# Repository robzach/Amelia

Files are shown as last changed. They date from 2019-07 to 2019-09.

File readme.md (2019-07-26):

# 7/19/19: radio weirdness

Note: this is my first entry into this log but very much not the first work done on this project.

I kept running into a failure to transmit error while I was trying to run `ranger_transmitter` and `multi_receiver_print_serial`. I checked the wiring repeatedly and couldn't diagnose the problem. I disconnected the SDA and SCL lines running to the ranger, thinking perhaps they were interfering with the transmission, but that didn't help either. It was especially confusing since I'd been using only lightly modified code, with a nearly identical hardware setup, that worked very well on the Empathy Machine project only about a month ago. (That hardware has continued to work.)

The Empathy Machine code uses an acknowledge packet to return data to the requesting radio, which is a clever way of having one receiving radio that many transmitters send things to: the "receiver" actually sends out packets to one radio at a time, and the recipient of each packet responds only when called on. This prevents collisions and worked just fine the last time I tried it, as I've mentioned.

Shifting to a simpler model, I tried using the `simple_rx` and `simple_tx` sketches (found in the `examples and tests` folder) which mercifully finally worked…with a caveat. For some reason, about half of the packets seemed to be dropped. As in, the transmitter was sending one packet per second, and the receiver would only blink about half the time. Very confusing behavior, for two radios which are a foot apart from each other on a table. Perhaps this is an environment (a university campus) where there's enough 2.4GHz traffic to interfere with these attempts.

One note: I'm watching the little hardware TX lights to see when the transmitter is sending and when the receiver is receiving, and that makes it obvious when they're mismatched (because the transmitter is blinking like twice as much as the receiver). However! The blinking is perfectly in lockstep right until I open the serial connection on the computer attached to the receiver. Are `Serial.println()` executions the problem here? I don't think it's a timing issue, because even when I'm only transmitting one packet a second it's still dropping like half of them. Don't know.

## Next step: wired

I spent more time trying to get these wireless modules to work, and began investigating the strange data loss behavior, but it's a dark rabbit hole. Instead, I'm going to eschew the radio feature entirely—it was only implemented as a way of simplifying the prototyping I want to do. Instead, I'll rewrite the code so the one "receiver" and all the "transmitters" are simply wired together. I'll use software serial on all of them so that I can plug into their hardware UART via the serial monitor to update and debug as needed. And I'll just run a bunch of long wires to each module: two for power, and two for data. Hopefully the cable runs won't be so long that there's data quality problems…probably a 10 foot run won't be too much.

I could just move towards the likely final installation version of this, namely using RS485 modules since that's a safe/reasonable way to move signals over any sort of distance, with easy cabling, etc.

# 7/25/19 wires, but still not quite there

Lots of work was left out of this log, but now I've got all the devices with wired connections on the table. (I never figured out what was wrong with the radio connections.)

Currently all 5 sensors are sharing a UART bus with the data requesting unit, which is plugged into a computer. I have installed diodes on the TX lines of each sensor Arduino (facing *into* the Arduino, counterintuitively) so that the line has transmission integrity, but it's still not quite working right.

I'm only using the UART for one-directional communication. The requesting unit sends a brief pulse into a wire every 1 second, and each remote Arduino has an interrupt that's triggered by a falling voltage on pin `2`, where that's plugged in. Then each unit waits a certain amount of time before sending its data back to the requesting unit on the UART bus.

Important finding: if the remote (sensor) Arduinos aren't plugged into power, but are plugged into ground, then the voltage of the outgoing trigger signal drops unacceptably. Probably an unpowered Arduino doesn't have high impedance on a digital pin, and lets some leakage through to the ground that it *is* plugged into. In conclusion: don't simply unplug power on remote Arduinos for troubleshooting, as it will kill the trigger signal.

Transmission time for the message `#0:1234` at 9600 baud is observed as 9.36ms on the scope. That's good; it means that giving each transmission at 20ms intervals should be plenty of deadband in between.

**Found the problem!** There was a tiny, invisible electrical fault: one of the yellow wires in the UART bus appears to have been mashed into a ground pin, always holding the TX line low. I rearranged the wires and it's fixed. Now all five devices are sending their own data to the requester, reliably.

Next up: try a higher data speed, hopefully while maintaining data integrity. Have been using 9600 baud, and I'll just leap up to 115200 to see what happens. If it's transmitting good data, then the messages can be crammed into a much narrower frame, and more messages can be sent per second overall.

Results: 19200 baud is the fastest baud rate that successfully transmits data across the ~6' twisted wires; above that the inductance and/or capacitance of the wire isn't getting good data to the far end. Of course, using RS485 transmitters would solve this problem entirely and permit for much higher data transmission rates. Requests for new data should be sent no more often than every 200ms, or data from the prior request will overlap and cause errors.

**Adding a Processing sketch** to graph the data, which is doing something, but not drawing good graphs yet.

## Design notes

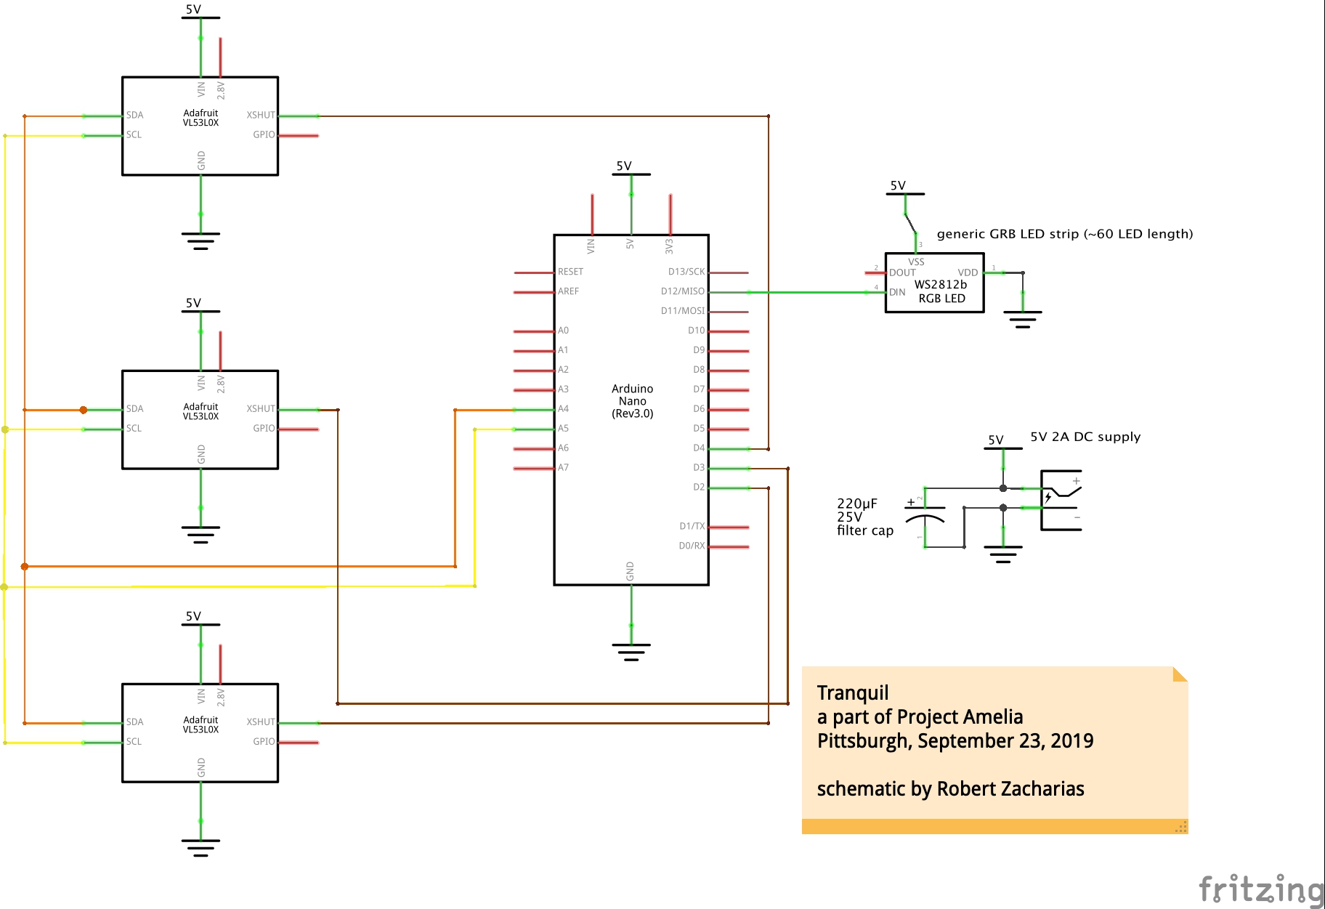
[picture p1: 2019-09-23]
production/electronics/Tranquil_schematic.jpg

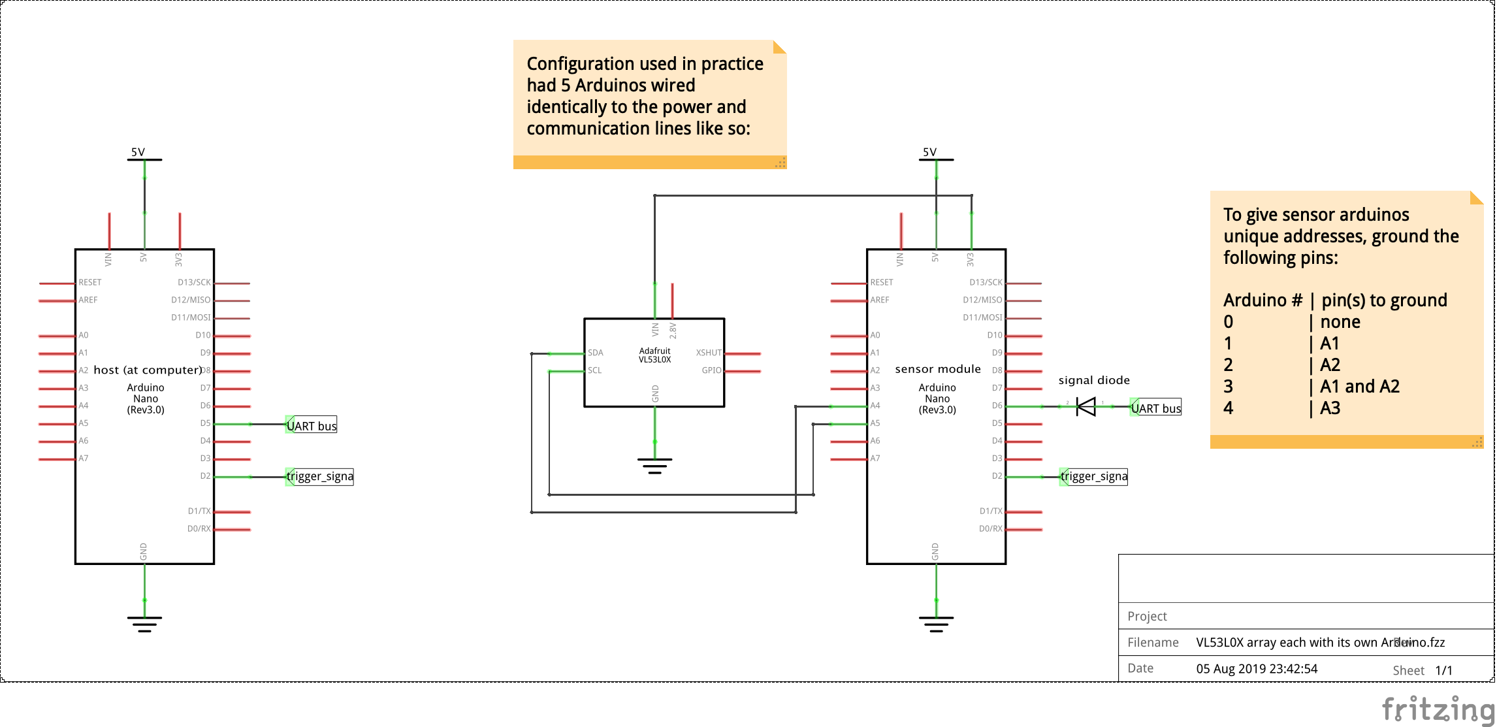
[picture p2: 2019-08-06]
earlier_development/schematics/VL53L0X array each with its own Arduino_schem.png

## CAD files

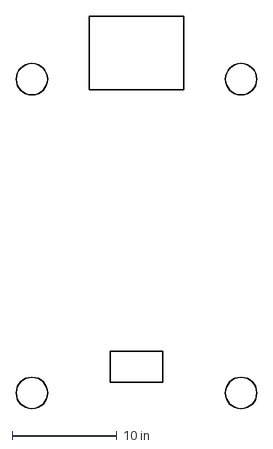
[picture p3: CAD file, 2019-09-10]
earlier_development/fabrication_drawings/test_sensor_cutout.dxf
23.0 x 37.5 in

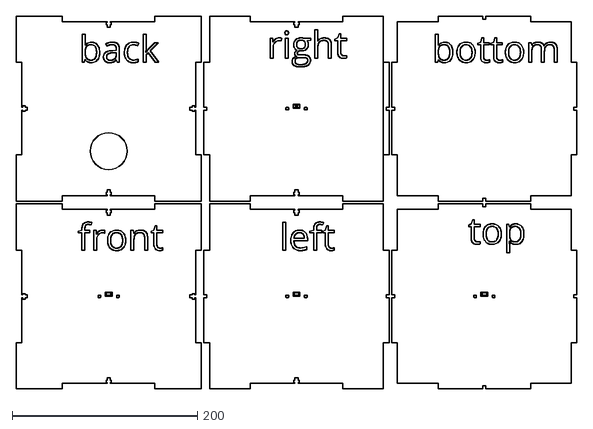
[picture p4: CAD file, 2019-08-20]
earlier_development/fabrication_drawings/#box_with_sensor_cutouts.dxf
606.0 x 403.0

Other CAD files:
earlier_development/fabrication_drawings/box_with_sensor_cutouts.dxf

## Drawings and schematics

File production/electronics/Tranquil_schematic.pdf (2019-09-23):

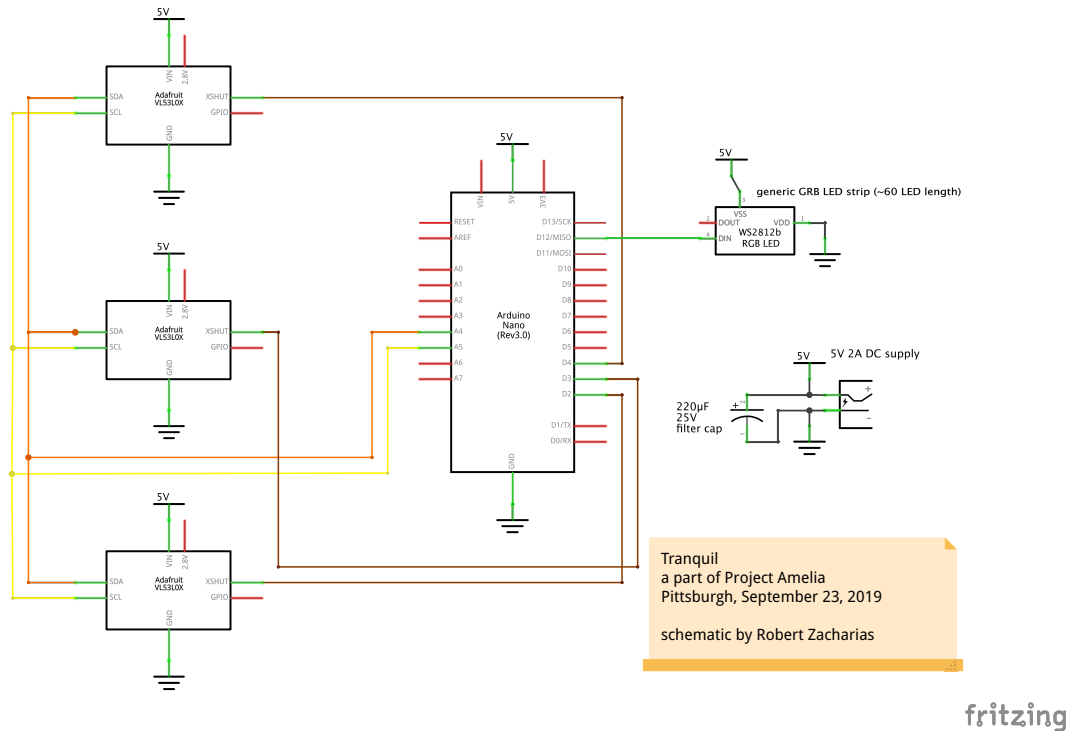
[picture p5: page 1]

Tranquil
a part of Project Amelia
Pittsburgh, September 23, 2019

schematic by Robert Zacharias

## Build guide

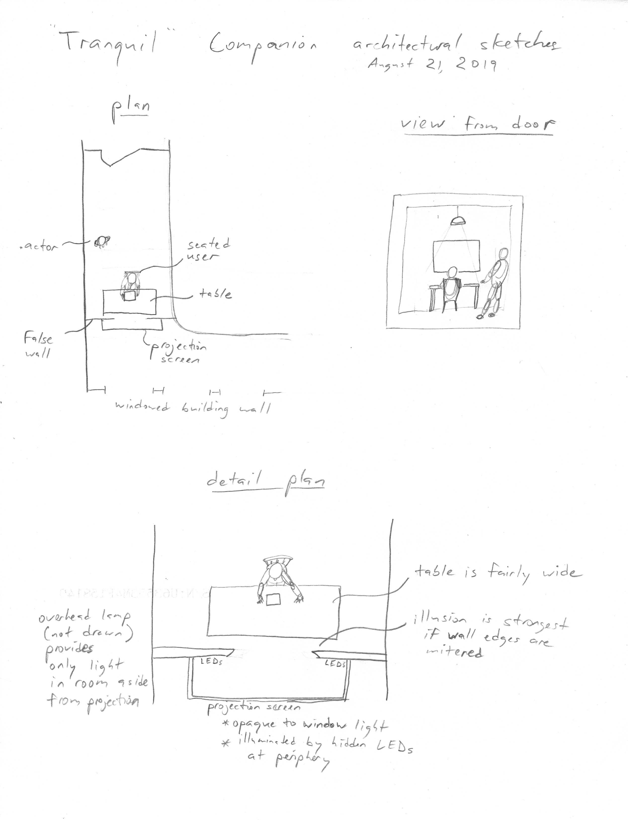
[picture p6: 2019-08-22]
earlier_development/fabrication_drawings/Tranquil Companion architectural sketch.jpeg

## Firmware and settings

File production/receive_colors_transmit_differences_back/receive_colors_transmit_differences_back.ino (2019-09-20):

// updating 9-8-19 with byte-based serial communication


#include <PololuLedStrip.h>
#include <Wire.h>
#include <VL53L0X.h>

//#define HIGH_SPEED

const int LED_STRIP_PIN = 12; // WS2801 LED strip data line is plugged into this pin

PololuLedStrip<LED_STRIP_PIN> ledStrip;
const int LED_COUNT = 60;
rgb_color colors[LED_COUNT]; // Create a buffer for holding the colors (3 bytes per color).

const int NUM_SENSORS = 3;
const byte START_ADDRESS = 29; // first I2C address to provision (the rest will increment)
const long SERIAL_SPEED = 57600; // serial communication baud rate

const int DEBUGPIN1 = 10; // used for oscope monitoring of various events

const bool DEBUG = false;

bool newDataRecd = false;
int counter = 0;

// incoming color data from Processing:
// a sensor instruction byte, three color bytes 0–254 each, a checksum, and a 255 terminator
byte readIn[6];

// data to return to Processing:
// three sensor positions, a checksum, and a 255 terminator
byte sendData[5];



VL53L0X sensor[NUM_SENSORS];
int sensorValues[NUM_SENSORS] = {}; // values to transmit


void setup() {
  Serial.begin(SERIAL_SPEED);
  Wire.begin();

  pinMode(DEBUGPIN1, OUTPUT);
  digitalWrite(DEBUGPIN1, LOW);

  // set up Arduino output pins to connect with each sensor's XSHUT (shutdown) input
  for (int i = 0; i < NUM_SENSORS; i++) {
    pinMode(i + 2, OUTPUT); // start at digital pin 2 and increment from there
    digitalWrite(i + 2, LOW); // shut down all the sensors to start with
  }

  // initialize each sensor individually
  for (int i = 0; i < NUM_SENSORS; i++) {

    digitalWrite(i + 2, HIGH); // turn them on one at a time
    delay(100); // wait a bit to ensure that sensor is ready to receive an instruction

    // assign a new address to that sensor
    sensor[i].init();
    sensor[i].setTimeout(500);
    sensor[i].setAddress(i + START_ADDRESS);
    if (DEBUG) Serial.println((String)"sensor: " + i + ", address: " + (i + START_ADDRESS));

#if defined HIGH_SPEED
    // reduce timing budget to 20 ms (default is about 33 ms)
    sensor[i].setMeasurementTimingBudget(20000);
#elif defined HIGH_ACCURACY
    // increase timing budget to 200 ms
    sensor[i].setMeasurementTimingBudget(200000);
#endif
  }
}

void loop() {
  // the serial event catches incoming color data and flips newDataRecd true
  if (newDataRecd) {
    writeColorsToLEDs();
    scanSensorsTransmitResponse();
    newDataRecd = false;
  }
}

void serialEvent() {
  while (Serial.available()) {
    readIn[counter] = Serial.read();
  }
  if (readIn[counter] == 255) { // terminator received
    if (checksumValid(readIn)) newDataRecd = true;
    counter = 0; // and reset counter

    // reply with checksum result followed by terminator
    //    Serial.write(checksumValid(readIn)); Serial.write(255);
    //    Serial.write(readIn, counter); // write values prior to terminator
    //    Serial.write(255); // and write a terminator at the end
  }
  else counter++; // otherwise, proceed through loop
}

void writeColorsToLEDs() {
  rgb_color color;
  color.green = readIn[1];
  color.red = readIn[2];
  color.blue = readIn[3];

  for (uint16_t i = 0; i < LED_COUNT; i++) colors[i] = color;

  // Write to the LED strip.
  // time to execute this write (with 60 LEDs) measured at ~4ms
  ledStrip.write(colors, LED_COUNT);
}

void scanSensorsTransmitResponse() {
  // scan only the sensors indicated by the zeroth byte received from Processing
  bool readSensor0 = readIn[0] & 0b1; // ones bit
  bool readSensor1 = (readIn[0] >> 1) & 0b1; // twos bit
  bool readSensor2 = (readIn[0] >> 2) & 0b1; // fours bit

//  readSensor0 = readSensor1 = readSensor2 = true;

  // array to hold values prior to reducing them to bytes
  int distVals[3];
  if (readSensor0) distVals[0] = sensor[0].readRangeSingleMillimeters();
  if (readSensor1) distVals[1] = sensor[1].readRangeSingleMillimeters();
  if (readSensor2) distVals[2] = sensor[2].readRangeSingleMillimeters();

//  for (int i = 0; i < 3; i++){
//    Serial.print(distVals[i]);
//    Serial.print(" "); 
//  } Serial.println();

  // slice millimeter values into 255 bins
  // assumes max meaningful distance is 500mm = 50cm
  for (int i = 0; i < 3; i++) {
    distVals[i] = map(constrain(distVals[i], 0, 500), 0, 500, 0, 254);
  }

  // buffer to hold values to write out, plus a checksum and a terminator at the end
  byte writeBuf[3 + 2] = {}; // need this to zero all values instead of holding over!!

  // load sliced values into byte array
  for (int i = 0; i < 3; i++) {
    writeBuf[i] = distVals[i];
  }

  // add checksum to penultimate position in writeBuf array
  for (int i = 0; i < 3; i++) {
    writeBuf[3] += (writeBuf[i] * (i + 1));
  } // checksum is computed: (0th data point + (1st data point * 2) + (2nd data point * 3) + ...)

  // finally, write value 255 to final position of array to serve as terminator
  writeBuf[3 + 1] = 255;

  Serial.write(writeBuf, 5);

  //
  //  for (int i = 0; i<5; i++){
  //    sendData[i] = writeBuf[i];
  //  }
  //
//    sendData[5] = 255; // last bit is terminator
}

// checksum should be at penultimate array position, and 255 (terminator) at the end
boolean checksumValid (byte * arrayIn) {
  // you can't run sizeof(array) because you just get the size of the pointer to that array
  // instead find the passed in array's length by finding the position of the 255 terminator
  int length = 0;
  while (arrayIn[length] < 255) length++;
  length++; // after above while() exits, length contains the index of the 255 value; increment to calculate length of array

  byte localChecksum = 0;
  // add zeroth through second-to-last element in incoming data
  for (int i = 0; i < length - 2; i++) {
    localChecksum += (arrayIn[i] * (i + 1));
  }

  // special case: change 255 checksum to 254
  if (localChecksum == 255) localChecksum = 254;

  //  localChecksum = arrayIn[0] + (arrayIn[1] * 2) + (arrayIn[2] * 3);

  // penultimate element of array is checksum, so compare to penultimate value read in for result
  return (localChecksum == arrayIn[length - 2]);
}

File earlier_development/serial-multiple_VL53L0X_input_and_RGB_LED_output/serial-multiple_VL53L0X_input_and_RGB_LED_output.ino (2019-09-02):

/*
    Multiple VL53L0X sensors are read via shared I2C bus; this is a data input to the device.
    It also has a short length of addressable RGB LED strip on it, which is a data output.

    Distance input information:

        Distance values are reported, space-delimited, via serial port. Sample data looks like:

        263 307 144 8190

        Note that the value 8190 is what the sensor typically reports when the target surface
        is out of range.

        Each VL53L0X sensor's wiring:

          VCC to Arduino 5V (red wire)
          GND to Arduino ground (black wire)
          SCL to Arduino A5 (yellow wire)
          SDA to Arduino A4 (white wire)
          XSHUT incrementally starting at Arduino digital pin 2 (brown wire)
          (first sensor wires XSHUT to Arduino pin 2, second sensor wires XSHUT to Arduino pin 3, etc.)

        Based on Pololu's VL53L0X example code; their original text below:

        "This example shows how to get single-shot range
        measurements from the VL53L0X. The sensor can optionally be
        configured with different ranging profiles, as described in
        the VL53L0X API user manual, to get better performance for
        a certain application. This code is based on the four
        "SingleRanging" examples in the VL53L0X API.
        The range readings are in units of mm."

    LED output information:

        The LED strip is wired VCC to the Arduino's 5V; ground to the Arduino's ground; and
        the signal pin goes to Arduino pin 12.

        Incoming data comes in the form "R,G,B" and must be delimited (though it need not be
        comma delimited necessarily). The serial to int process relies on parseInt, which can be blocking,
        so I might need to work on it.

        The logic is drawn straight from Pololu's example sketch, "LedStripColorTester."

  Robert Zacharias, 8-12-19

*/

#include <Wire.h>
#include <VL53L0X.h>
#include <PololuLedStrip.h>

const int NUM_SENSORS = 4;
const byte START_ADDRESS = 29; // first I2C address to provision (the rest will increment)
const long SERIAL_SPEED = 9600; // serial communication baud rate
const int LED_STRIP_PIN = 12; // WS2801 LED strip data line is plugged into this pin

// Set this bool to true for some serial debugging messages
// (Note: these messages will clutter the serial feedback, probably making it unreadable
// to software that's parsing out the returned distance values.)
const bool DEBUG = false;

// flag to send data only after spoken to: go true when data received, then transmit
// data back, then go false
bool transmitNow = false;

PololuLedStrip<LED_STRIP_PIN> ledStrip;
const int LED_COUNT = 60;
rgb_color colors[LED_COUNT]; // Create a buffer for holding the colors (3 bytes per color).

VL53L0X sensor[NUM_SENSORS];


// Uncomment the below #define to use long range mode. This
// increases the sensitivity of the sensor and extends its
// potential range, but increases the likelihood of getting
// an inaccurate reading because of reflections from objects
// other than the intended target. It works best in dark
// conditions.

//#define LONG_RANGE


// Uncomment ONE of these two #defines to get
// - higher speed at the cost of lower accuracy OR
// - higher accuracy at the cost of lower speed

//#define HIGH_SPEED
//#define HIGH_ACCURACY


void setup()
{
  Serial.begin(SERIAL_SPEED);
  Serial.setTimeout(100); // only wait 100 milliseconds to parse malformed input
  Wire.begin();

  // set up Arduino output pins to connect with each sensor's XSHUT (shutdown) input
  for (int i = 0; i < NUM_SENSORS; i++) {
    pinMode(i + 2, OUTPUT); // start at digital pin 2 and increment from there
    digitalWrite(i + 2, LOW); // shut down all the sensors to start with
  }

  // initialize each sensor individually
  for (int i = 0; i < NUM_SENSORS; i++) {

    digitalWrite(i + 2, HIGH); // turn them on one at a time
    delay(100); // wait a bit to ensure that sensor is ready to receive an instruction

    // assign a new address to that sensor
    sensor[i].init();
    sensor[i].setTimeout(500);
    sensor[i].setAddress(i + START_ADDRESS);
    if (DEBUG) Serial.println((String)"sensor: " + i + ", address: " + (i + START_ADDRESS));

#if defined LONG_RANGE
    // lower the return signal rate limit (default is 0.25 MCPS)
    sensor[i].setSignalRateLimit(0.1);
    // increase laser pulse periods (defaults are 14 and 10 PCLKs)
    sensor[i].setVcselPulsePeriod(VL53L0X::VcselPeriodPreRange, 18);
    sensor[i].setVcselPulsePeriod(VL53L0X::VcselPeriodFinalRange, 14);
#endif

#if defined HIGH_SPEED
    // reduce timing budget to 20 ms (default is about 33 ms)
    sensor[i].setMeasurementTimingBudget(20000);
#elif defined HIGH_ACCURACY
    // increase timing budget to 200 ms
    sensor[i].setMeasurementTimingBudget(200000);
#endif
  }
}

void loop()
{
  if (transmitNow) writeSensorValuesOut();
  readLEDColorIn();
}

void writeSensorValuesOut() {
  for (int i = 0; i < NUM_SENSORS; i++) {
    Serial.print(sensor[i].readRangeSingleMillimeters());
    if (sensor[i].timeoutOccurred() && DEBUG) {
      Serial.print(" TIMEOUT");
    }
    if (i != NUM_SENSORS - 1) Serial.print(' '); // space delimit between values
  }
  Serial.println();
  transmitNow = false; // switch flag to not send data
}

void readLEDColorIn() {
  if (Serial.available())
  {
    char c = Serial.peek();
    if (!(c >= '0' && c <= '9'))
    {
      Serial.read(); // Discard non-digit character
    }
    else
    {
      // Read the color from the computer.
      rgb_color color;
      color.red = Serial.parseInt();
      color.green = Serial.parseInt();
      color.blue = Serial.parseInt();

      // Update the colors buffer.
      for (uint16_t i = 0; i < LED_COUNT; i++)
      {
        colors[i] = color;
      }

      // Write to the LED strip.
      ledStrip.write(colors, LED_COUNT);

      transmitNow = true; // switch flag to send data

      if (DEBUG) {
        Serial.print("Showing color: ");
        Serial.print(color.red);
        Serial.print(",");
        Serial.print(color.green);
        Serial.print(",");
        Serial.println(color.blue);
      }
    }
  }
}

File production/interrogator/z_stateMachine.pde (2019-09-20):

void stateMachine() {
  // only print console feedback "entering mode: MODE" if changed from prior mode (for debugging)
  boolean change = (prevMode != mode) ? true : false;

  switch (mode) {
  case ORIENTATION:
    if (change) {
      println("entering mode: " + mode);
      prevMode = mode;
      // when just entering mode, set counter to 0
      stageCounter = 0; // used to step through stages in orientation
    }
    orientation(); 

    // if start signal received while in Orientation, move to idle
    if (braceletTap) {
      braceletTap = false; // flip it back after acknowledge
      mode = Mode.IDLE;
    }
    break;
  case INTERROGATION:
    if (change) {
      println("entering mode: " + mode);
      prevMode = mode;
      stageCounter = 0; // reset stage counter for new mode
    }
    interrogation();

    // if start signal received while in interrogation, move to idle
    if (braceletTap) {
      braceletTap = false; // flip it back after acknowledge
      mode = Mode.IDLE;
    }
    break;
  case TERMINATION: 
    if (change) {
      println("entering mode: " + mode);
      prevMode = mode;
    }
    termination(); 
    break;
  case IDLE:
  default:
    if (change) {
      println("entering mode: " + mode);
      prevMode = mode;

      // triggers once upon entering IDLE mode
      // slow fading in and out of white
      breaths[0] = new Breathe(true, 0, 15000);  // red
      breaths[1] = new Breathe(true, 1, 15000); // green
      breaths[2] = new Breathe(true, 2, 15000); // blue
    }

    idle();

    // if start signal received, move to orientation mode
    if (braceletTap) {
      braceletTap = false; // flip it back after acknowledge
      mode = Mode.ORIENTATION;
    }

    break;
  }
}

long startTime = 0;

void idle() {
  if (millis() - startTime > 1000) {
    startTime = millis();
  }

  // updates all breathing functions, only for those objects currently wanting to be run
  for (Breathe breath : breaths) {
    if (breath.getActive()) {
      breath.pollBreathe();
    }
  }
}

void orientation() {
  // start timer to begin
  if (stageCounter == 0) {
    startTime = millis(); 
    stageCounter = 1;
    for (int i = 0; i < 3; i++) colors[i] = 0; // zero out colors
    transmitBytes();
  }

  // start with left-side-of-box sensor training for 10 seconds
  if (stageCounter == 1) {
    if (millis() - startTime < 10000) redScale();
    else {
      stageCounter = 2;
      startTime = millis();
      for (int i = 0; i < 3; i++) colors[i] = 0; // zero out colors
    }
  }


  // right-side-of-box sensor training for 10 seconds
  if (stageCounter == 2) {
    if (millis() - startTime < 10000) blueScale();
    else {
      stageCounter = 3;
      startTime = millis();
      for (int i = 0; i < 3; i++) colors[i] = 0; // zero out colors
    }
  }

  // top-side-of-box sensor training for 10 seconds
  if (stageCounter == 3) {
    if (millis() - startTime < 10000) greenScale();
    else {
      stageCounter = 4;
      startTime = millis();
      for (int i = 0; i < 3; i++) colors[i] = 0; // zero out colors
    }
  }

  //once complete, revert to IDLE mode
  if (stageCounter == 4) mode = Mode.INTERROGATION;
}


void interrogation() {
  // pulse different lights up and down through a sequence of brightnesses
  // these are described by the switch(case) statements below (as is the 

  if (millis() > nextSingleTime) {
    int stepTime = 0;
    switch(counter) {
    case 0:
      breaths[0] = new Breathe(true, 0, 2000);  // red breathing sequence
      stepTime = 10000;
      break;
    case 1:
      breaths[0].setActive(false);
      breaths[1] = new Breathe(true, 1, 1000); // green breathing sequence
      stepTime = 10000;
      break;
    case 2:
      breaths[1].setActive(false);
      breaths[2] = new Breathe(true, 2, 750); // blue breathing sequence
      stepTime = 10000;
      break;
    case 3:
      breaths[2].setActive(false);
      breaths[1] = new Breathe(true, 0, 1000); // red breathing sequence
      stepTime = 10000;
      break;
    case 4:
      breaths[1].setActive(false);
      breaths[0] = new Breathe(true, 0, 1000); // red breathing sequence
      stepTime = 500;
      break;
    case 5:
      // note that breaths[2] is still running from the previous case
      breaths[2] = new Breathe(true, 2, 1000); // blue sequence to run concurrently with red
      stepTime = 9500;
      break;
    case 6:
      breaths[0].setActive(false); // turn everything off
      breaths[2].setActive(false); // turn everything off
      break;
    case 7:
      counter = 0; // counter reset added by Mike to fix bug
      mode = Mode.TERMINATION;
      break;
    default:  // if it breaks, go to IDLE mode
      mode = Mode.IDLE;
      break;
    }
    counter++; // increment for next case to get called next time
    for (int i = 0; i < 3; i++) colors[i] = 0; // zero out colors in between steps
    nextSingleTime = millis() + stepTime; // set up next time this if goes true
  }

  // updates all breathing functions, only for those objects currently wanting to be run
  for (Breathe breath : breaths) {
    if (breath.getActive()) {
      breath.pollBreathe();
    }
  }
}

void termination() {

  // flashes red and blue a bunch of times quickly
  // (blocking code! Probably doesn't matter at this point, though)
  for (int i = 0; i < 20; i++) {
    colors[0] = 254; // red
    colors[2] = 0; // no blue
    transmitBytes();
    delay(100);
    colors[0] = 0; // no red
    colors[2] = 255; // blue
    transmitBytes();
    delay(100);
  }
  mode = Mode.IDLE;
}


/*
old version using individually called pollBreathe() functions
 void interrogation() {
 // pulse different lights up and down through a sequence of brighnesses
 
 if (stageCounter == 0) {
 startTime = millis(); 
 for (int i = 0; i < 3; i++) colors[i] = 0; // zero out colors
 transmitBytes();
 stageCounter = 1;
 }
 
 if (stageCounter == 1) {
 breaths[0] = new Breathe(true, 0, 2000);  // begin red breathing sequence
 startTime = millis();
 stageCounter = 2;
 }
 
 if (stageCounter == 2) {
 if (millis() - startTime < 10000) { // if it's been less than 10 seconds
 breaths[0].pollBreathe(); // update that one breath command
 println(breaths[0].testBreathe());
 } else { // it's been more than 10 seconds
 breaths[1] = new Breathe(2, 1500); // begin blue breathing sequence
 for (int i = 0; i < 3; i++) colors[i] = 0; // zero out colors
 startTime = millis();
 stageCounter = 3;
 }
 }
 
 if (stageCounter == 3) {
 if (millis() - startTime < 10000) { 
 breaths[1].pollBreathe(); // run breaths[1]
 } else {
 breaths[2] = new Breathe(1, 1000);
 for (int i = 0; i < 3; i++) colors[i] = 0; // zero out colors
 startTime = millis();
 stageCounter = 4;
 }
 }
 
 if (stageCounter == 4) {
 if (millis() - startTime < 10000) { 
 breaths[2].pollBreathe(); // run breaths[2]
 } else {
 stageCounter = 5;
 }
 }
 
 if (stageCounter == 5) mode = Mode.IDLE;
 }
 */

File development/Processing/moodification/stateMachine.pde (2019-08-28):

void stateMachine() { //<>//
  // only print console feedback "entering MODE mode" if changed from prior mode (for debugging)
  boolean change = (prevMode != mode) ? true : false;

  switch (mode) {
  case INTRO:
    if (change) {
      println("entering " + mode + " mode");
      prevMode = mode;
    }
    rangerTrainingSequence();
    break;
  case CALMING:
    if (change) {
      println("entering " + mode + " mode");
      prevMode = mode;
    }
    calming(); 
    break;
  case DISORIENTATION:
    if (change) {
      println("entering " + mode + " mode");
      prevMode = mode;
    }
    disorientation(); 
    break;
  case INTERROGATION:
    if (change) {
      println("entering " + mode + " mode");
      prevMode = mode;
    }
    interrogation(); 
    break;
  case TERMINATION: 
    if (change) {
      println("entering " + mode + " mode");
      prevMode = mode;
    }
    termination(); 
    break;
  case IDLE: 
  default:
    if (change) {
      println("entering " + mode + " mode");
      prevMode = mode;
    }
    waitForStartSignal(); 
    break;
  }
}

long startTime = 0; 

void rangerTrainingSequence() {

  // start timer to begin
  if (stageCounter == 0) {
    startTime = millis();
    stageCounter = 1;
  }

  // run redAdjuster for 10 seconds
  if (stageCounter == 1) {
    if (millis() - startTime < 10000) redAdjuster();
    else {
      stageCounter = 2;
      startTime = millis();
    }
  }

  // run blueAdjuster for 10 seconds
  if (stageCounter == 2) {
    if (millis() - startTime < 10000) blueAdjuster();
    else {
      stageCounter = 3;
      startTime = millis();
    }
  }

  // run greenAdjuster for 10 seconds
  if (stageCounter == 3) {
    if (millis() - startTime < 10000) greenAdjuster();
    else {
      startTime = millis(); // reset timer
      mode = Mode.DISORIENTATION; // jump to next mode
    }
  }
}

void disorientation() {
  //greenBreathe(0);
  //redBreathe();
  //blueBreathe(0);

  if (millis() - startTime < 10000) redBounce(300); // run redBounce for 10 seconds
  else  mode = Mode.TERMINATION; // jump to next mode
}

void interrogation() {
}

void termination() {
  // fade all up to white and then back down to black
  for (int i = 0; i < 256; i++) {
    writeOut(i + "," + i + "," + i + "\n");
    delay(10);
  }
  for (int i = 255; i > 0; i--) {
    writeOut(i + "," + i + "," + i + "\n");
    delay(10);
  }
  mode = Mode.IDLE;
}

void waitForStartSignal() {
}

float redBreathe() {
  // establishes a breathing goal (driven via sine) for hand movement by left hand

  // used for running average computation; closer to 0 is longer memory and closer to 1 is faster updating
  float decayRate = 0.03; 

  float sinArgument = map(millis() % breathingTempo, 0, breathingTempo, 0, TWO_PI); // feed sine [0,2*PI] based on millis()
  float goal = map (sin(sinArgument), -1, 1, 0, 500) ; // turn sine's output to 0 to 500 (millimeters)
  float breatheDelta = goal - left;
  runningAverageDelta = (breatheDelta * decayRate) + (runningAverageDelta * (1-decayRate));
  //println("breathe goal = " + goal + ", current position = " + left + ", delta = " + breatheDelta + ", runningAverageDelta = " + runningAverageDelta);

  //demonstrate the breathing goal with the red LED output
  int redVal = int(map(goal, 0, 500, 0, 255));
  //writeOut(redVal + ",0,0\n");

  pushMatrix();
  translate(TASKAREALEFTEDGE, 300);
  fill(255);
  text("red is goal, yellow is current position\nwhite line is delta\nrunningAverageDelta = " + runningAverageDelta +
    "\nbreatheDelta = " + breatheDelta, 0, 20);
  noStroke();
  fill(255, 0, 0);
  ellipse( map(goal, 0, 500, 200, 0), 0, 20, 20); // goal dot (note flipped axis)
  fill(255, 255, 0);
  ellipse( map(left, 0, 500, 200, 0), 0, 10, 10); // current position dot (note flipped axis)
  stroke(255);

  float graphRunningAverageDelta = map(runningAverageDelta, 0, 500, 0, 200);
  line(map(left, 0, 500, 200, 0), 0, map(left, 0, 500, 200, 0) - graphRunningAverageDelta, 0); 

  popMatrix();

  return runningAverageDelta;
}


float blueBreathe(int sync) {
  // establishes a breathing goal (driven via sine) for hand movement by right hand

  // used for running average computation; closer to 0 is longer memory and closer to 1 is faster updating
  float decayRate = 0.03; 

  // if argument "sync" is 0, run in parallel to redBreathe, otherwise run them 180º separately
  float sinArgument;
  if (sync == 0) sinArgument = map(millis() % breathingTempo, 0, breathingTempo, 0, TWO_PI); // feed sine [0,2*PI] based on millis()
  else sinArgument = map(millis() % breathingTempo, 0, breathingTempo, TWO_PI, 0); // or to put it 180º out of phase, feed it[2*PI,0]
  float goal = map (sin(sinArgument), -1, 1, 0, 500) ; // turn sine's output to 0 to 500 (millimeters)
  float breatheDelta = goal - right;
  runningAverageDelta = (breatheDelta * decayRate) + (runningAverageDelta * (1-decayRate));
  //println("breathe goal = " + goal + ", current position = " + left + ", delta = " + breatheDelta + ", runningAverageDelta = " + runningAverageDelta);

  //demonstrate the breathing goal with the blue LED output
  int blueVal = int(map(goal, 0, 500, 0, 255));
  //writeOut(redVal + ",0,0\n");

  pushMatrix();
  translate(TASKAREALEFTEDGE+250, 300);
  fill(255);
  text("blue is goal, yellow is current position\nwhite line is delta\nrunningAverageDelta = " + runningAverageDelta +
    "\nbreatheDelta = " + breatheDelta, 0, 20);
  noStroke();
  fill(0, 0, 255);
  ellipse( map(goal, 0, 500, 0, 200), 0, 20, 20); // goal dot (not flipped: moving to right)
  fill(255, 255, 0);
  ellipse( map(right, 0, 500, 0, 200), 0, 10, 10); // current position dot (not flipped: moving to right)
  stroke(255);

  float graphRunningAverageDelta = map(runningAverageDelta, 0, 500, 0, 200);
  line(map(right, 0, 500, 0, 200), 0, map(right, 0, 500, 0, 200) + graphRunningAverageDelta, 0); 

  popMatrix();

  return runningAverageDelta;
}
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

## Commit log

2019-07-19 many updates, though still getting a transmit error which prevents any radio stuff from working
    [multi_receiver_print_serial.ino, ranger_transmitter.ino]
2019-07-19 added test code for wireless communication, later abandoned as too buggy for unkonwn reason
    [simple_rx.ino, simple_rx_with_ranger_data.ino, simple_tx.ino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]
2019-07-25 call_listen and listen_respond are working as currently configured.
2019-07-26 first pass at a Processing sketch to read and graph the data (not working yet)
    [graph.pde]
2019-07-26 these are the actual working files for wired communication; those in <a44183> were *not* the correct, working ones
    [call_listen.ino, listen_respond.ino]
2019-08-05 starting schematic of multi-Arduino VL53L0X array
    [VL53L0X array each with its own Arduino.fzz]
2019-08-06 completed schematic of V53L0X-and-Arduino array
    [VL53L0X array each with its own Arduino.fzz]
2019-08-08 initial upload; sketch is working reading multiple sensors
2019-08-09 drawing for simple box fabrication
    [box_with_sensor_cutouts.dxf]
2019-08-09 test expansion of cutout for VL53L0X
    [test_sensor_cutout.dxf]
2019-08-09 updated with bigger sensor holes and using R14 DXF format in a bid to make the units work automatically
    [box_with_sensor_cutouts.dxf]
2019-08-13 initial commit; currently does a serial read but not repeatedly writing
2019-08-13 added simple sample of how to send color data (not yet reliable)
2019-08-15 reordered code for legibility; changed to space-delimited data; fixed bug where final data point was being missed
    [graph.pde]
2019-08-20 organized many files/folders
    [VL53L0X array each with its own Arduino.fzz, box_with_sensor_cutouts.dxf, test_sensor_cutout.dxf]
2019-08-20 added fabrication drawings and moved files to earlier_development
    [#box_with_sensor_cutouts.dxf]
2019-08-21 further work on state machine, including eliminating blocking code as much as possible (no more loops). Top sensor data added as well. Intro sequence more fully fleshed out.
2019-09-01 adding SPI communication folder
2019-09-02 adding Processing SPI file
2019-09-02 tried different serial ports, nothing seemed to be working to communicate with the Arduino
2019-09-02 added flag to only send serial data when it's received, this may have broken communication but it's not clear
    [serial-multiple_VL53L0X_input_and_RGB_LED_output.ino]
2019-09-06 closer to communication purely by byte arrays (faster, less error prone?)
    [writing_bytes_for_color.pde]
2019-09-08 successfull sending bytes from Processing to Arduino, parsing, adding 1 to each value, sending back. *NOT* successfully parsing reply on Processing side.
2019-09-08 this file actually successfully sends values 0–254, Arduino reads and responds, and it turns returned values into ints correctly
    [simpler_byte_array_writing_reading.pde]
2019-09-08 successfully sending byte data from Processing to Arduino, checksumming, and replying to Processing
2019-09-09 cranked serial speed up to 57600 without apparent data integrity loss. Saves a couple milliseconds.
2019-09-10 moved all stale development work into earlier_development
    [#box_with_sensor_cutouts.dxf, box_with_sensor_cutouts.dxf, test_sensor_cutout.dxf]
2019-09-10 renamed to intended file for all current development
2019-09-10 currently running redAdjuster part of orientation using state machine, but not successfully moving on to green or blue for unknown reason(s)
2019-09-11 short interrogation sequence plays, but so far without feedback
    [interrogator.pde, z_stateMachine.pde]
2019-09-12 using much more legible and shorter switch(case) structure in interrogation mode
    [interrogator.pde, z_stateMachine.pde]
2019-09-19 switched color order to green, red, blue to match LEDs we're using
2019-09-20 Mike found and squashed a bug in the interrogation counter
    [z_stateMachine.pde]
2019-09-22 moved currently production software to production folder
2019-09-23 initial commit of schematic, as based on production wiring
    [Tranquil_schematic.fzz]
2019-09-23 added way-better-printing PDF
